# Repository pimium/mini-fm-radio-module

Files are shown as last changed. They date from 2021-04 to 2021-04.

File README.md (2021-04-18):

# FM stereo receiver module


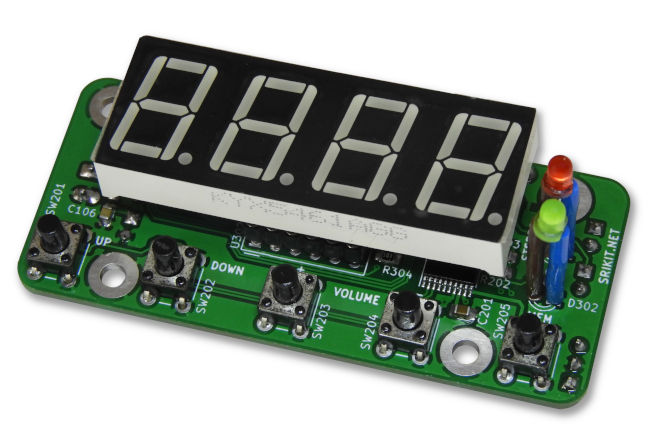
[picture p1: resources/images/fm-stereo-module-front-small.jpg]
KT0005


This is an RDA5807 based FM stereo radio module. This module is designed to replace old, low-voltage, analog FM stereo receiver modules. Like many digital receivers, this module also got auto scanning, station memory, and digital volume control. This module can driver using 5V to 9V DC power source.

The frequency range of the receiver is 88MHz to 108MHz. The auto scanner of this module can tune the receiver with 25kHz increments in up and down directions. 

The memory manager available with the current firmware can hold up to 10 stations in MCU EEPROM. 

AF output power of this module is not sufficient to handle the pair of speakers. To drive speakers, this module needs to pair with a stereo AF power amplifier kit/module.

This is an open-source hardware project. All the design files, [documentation](https://github.com/srikit/mini-fm-radio-module/wiki), and firmware source code are available to download at the [project source repository](https://github.com/srikit/mini-fm-radio-module). Content of this project is distributed under the terms of the following license:

 - Hardware License: [CERN-OHL-W](https://opensource.org/CERN-OHL-W)
 - Software License: [GNU GPL 3.0](https://github.com/srikit/mini-fm-radio-module/blob/main/LICENSE)
 - Documentation License: [CC BY 4.0](https://creativecommons.org/licenses/by/4.0)

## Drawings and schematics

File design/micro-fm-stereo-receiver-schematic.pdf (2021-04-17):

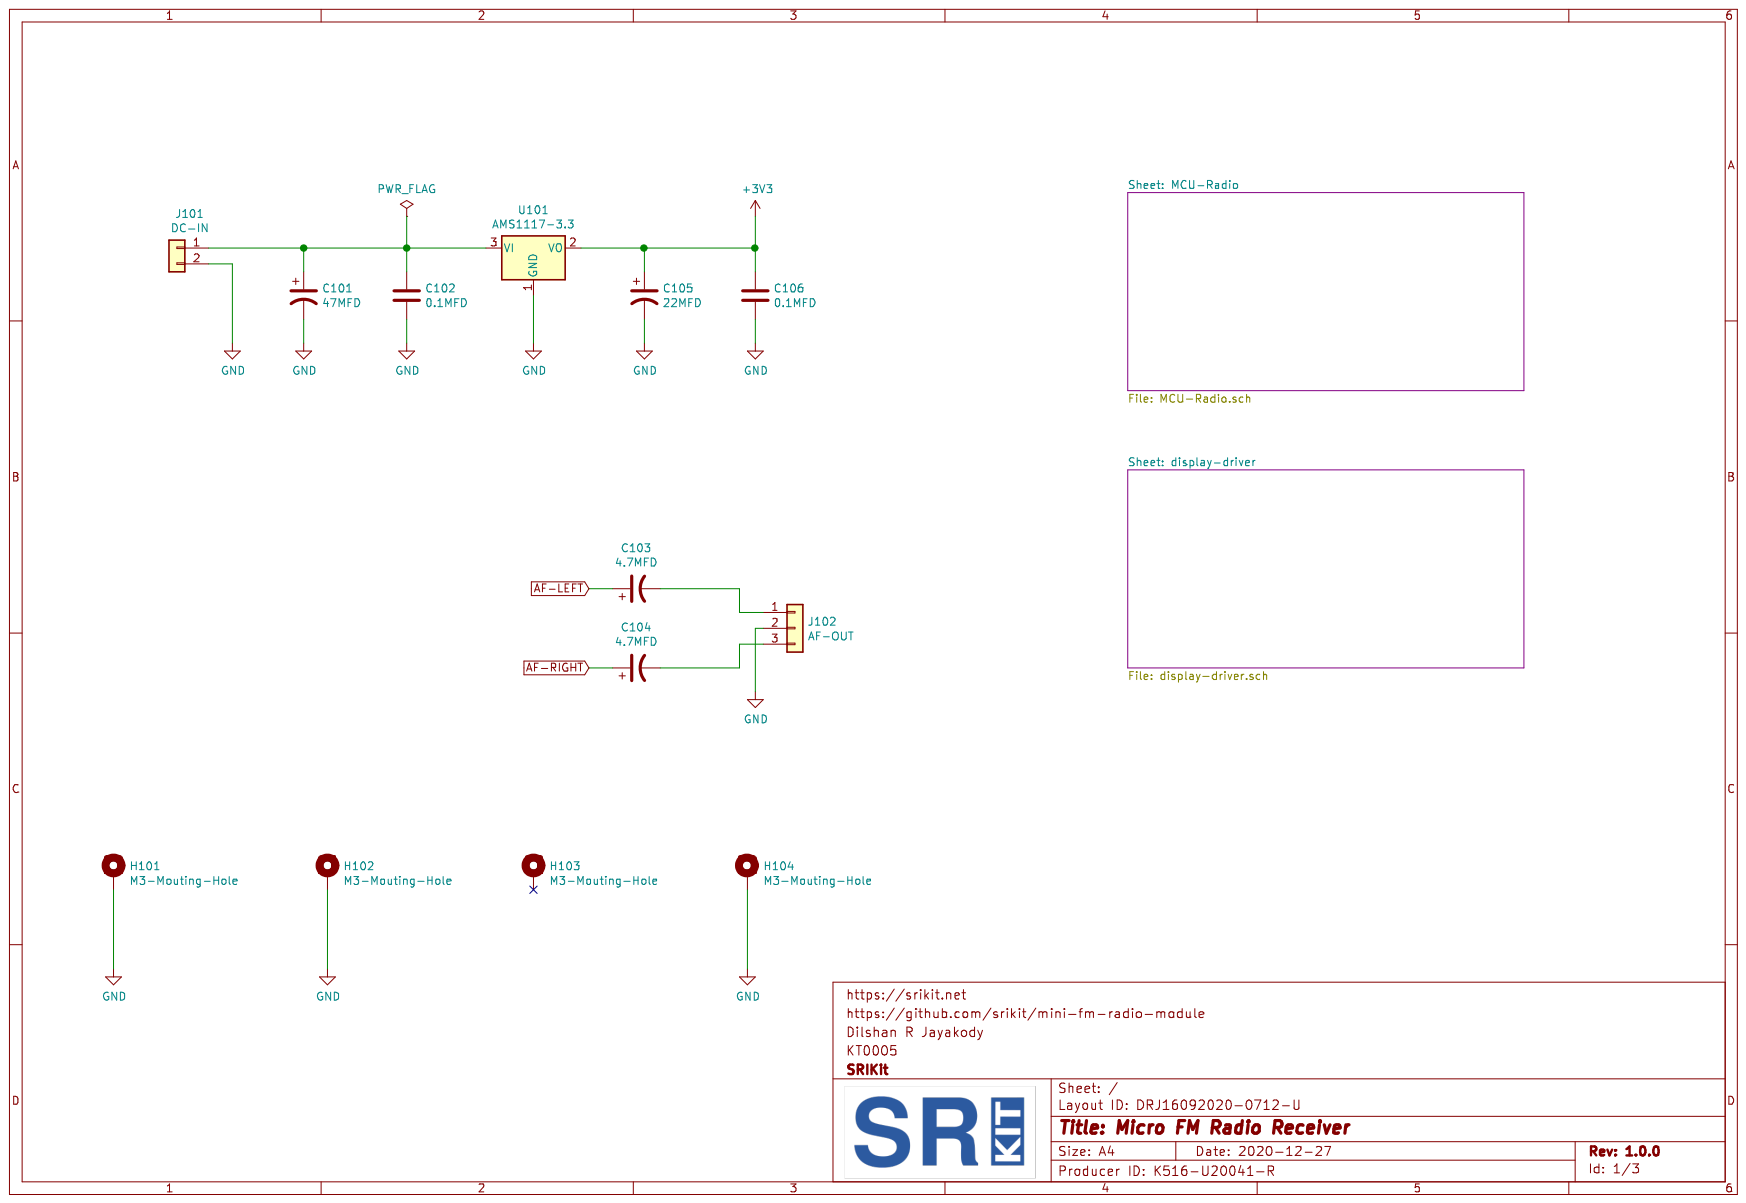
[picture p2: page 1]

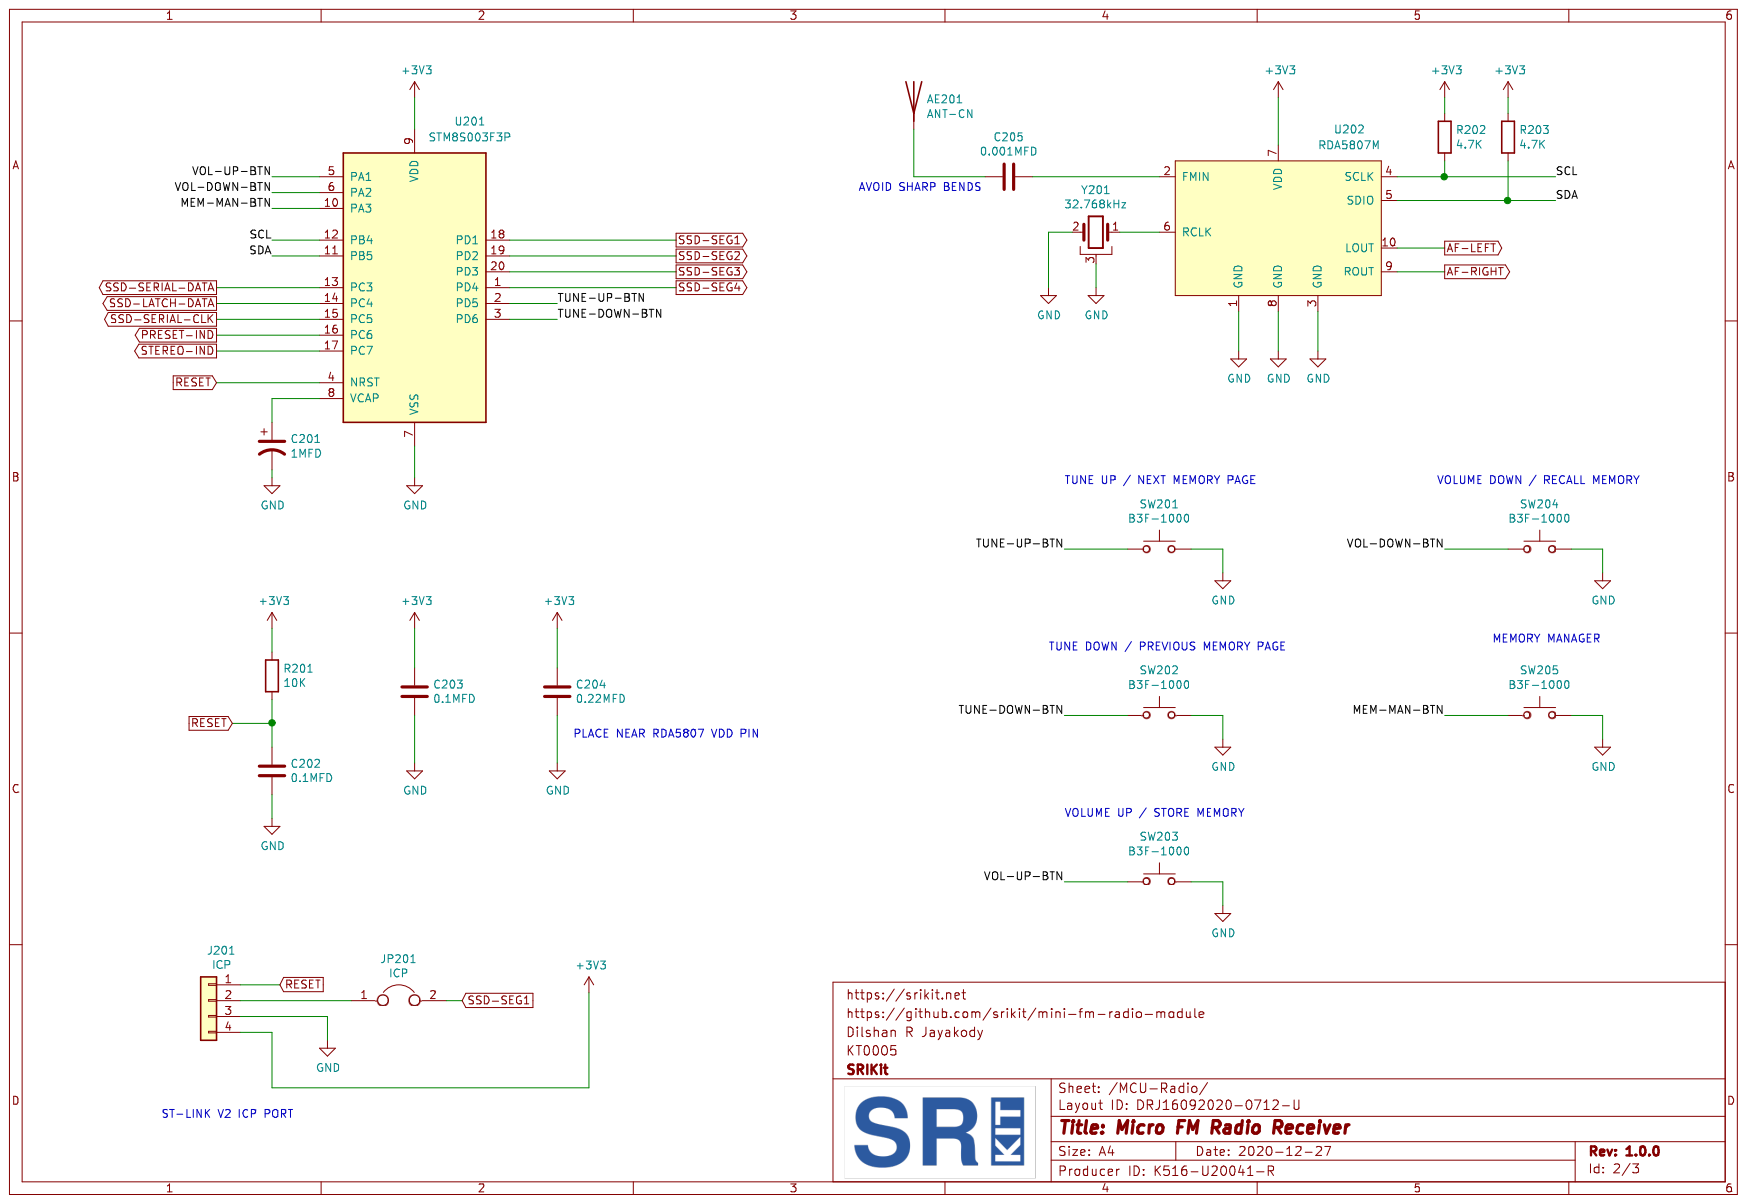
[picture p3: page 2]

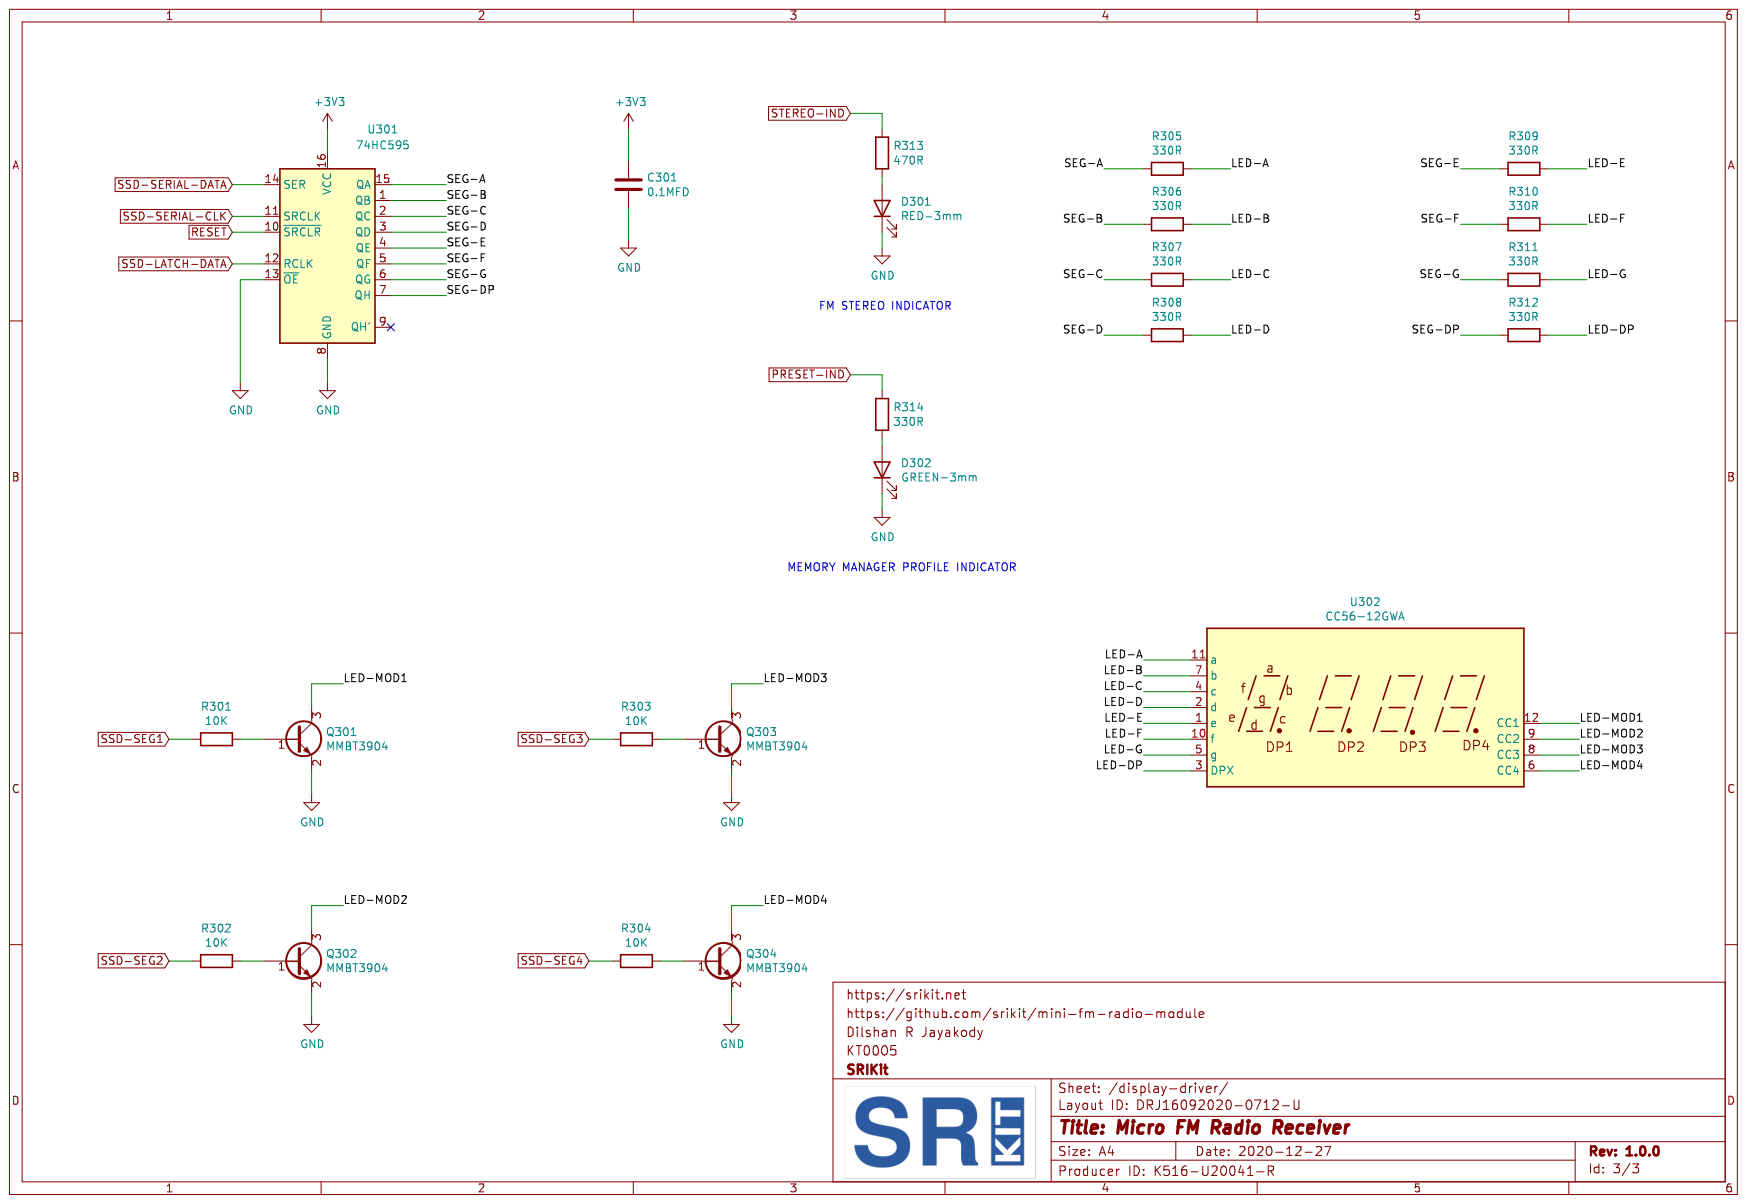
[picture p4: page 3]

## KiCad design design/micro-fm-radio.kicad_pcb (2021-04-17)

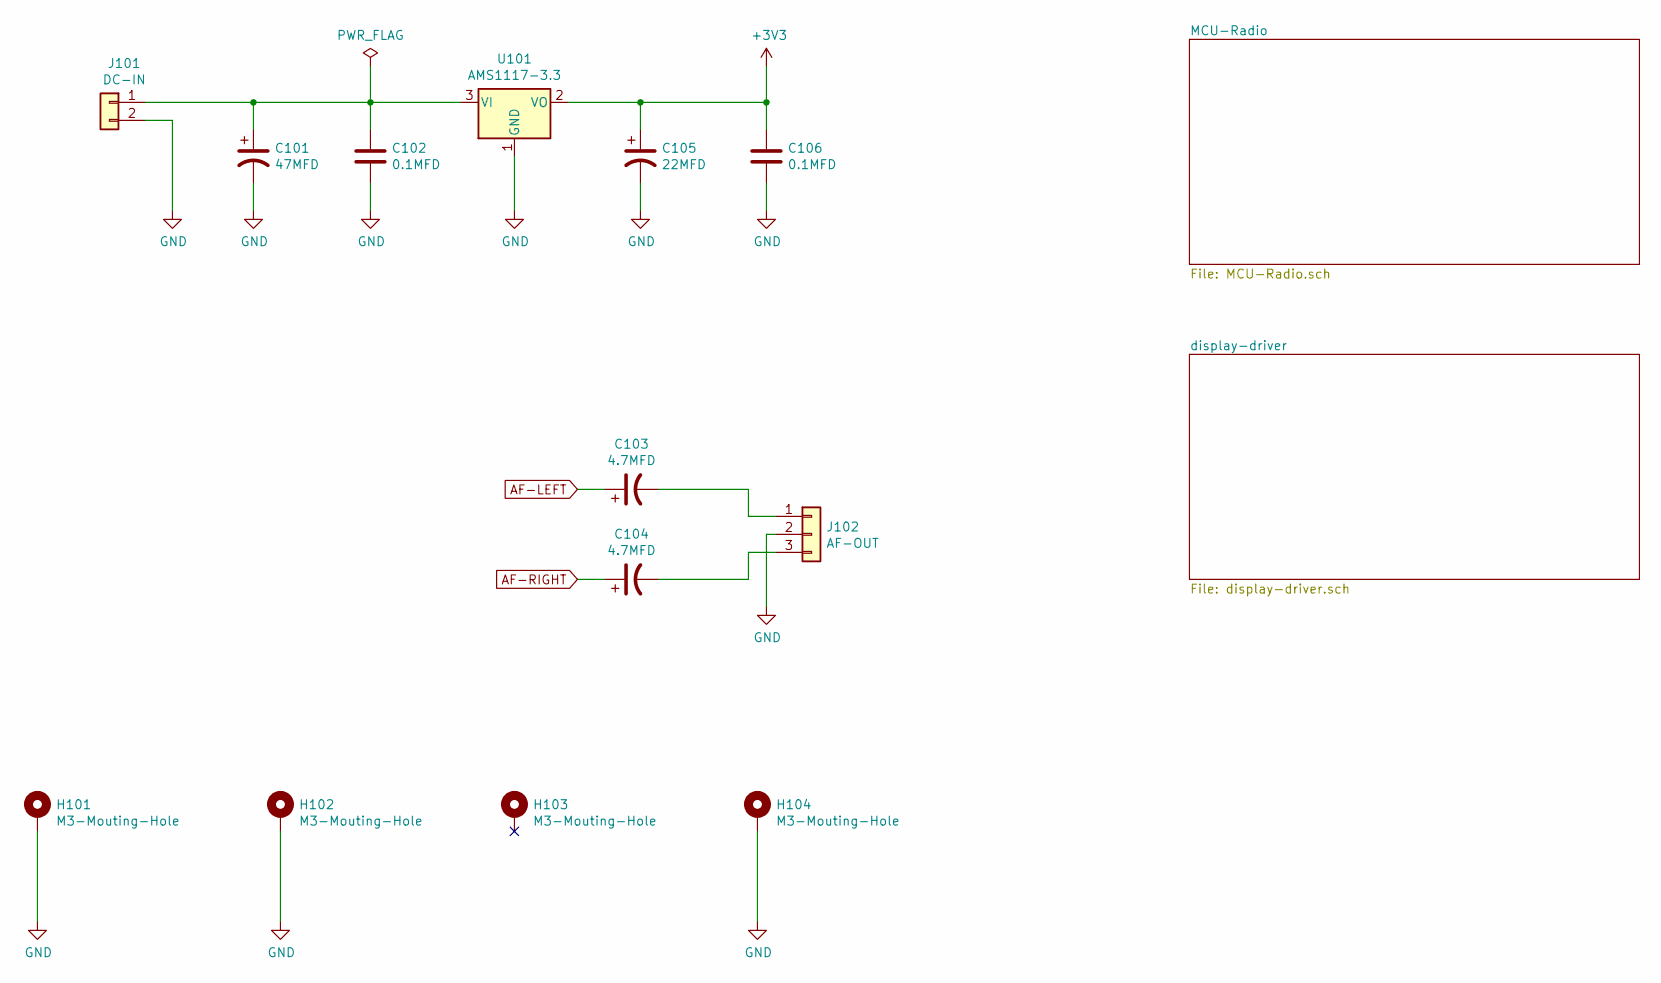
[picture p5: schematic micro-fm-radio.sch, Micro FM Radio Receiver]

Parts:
C101: 47MFD; CP_Radial_D5.0mm_P2.50mm
C102, C106: 0.1MFD; C_0805_2012Metric_Pad1.18x1.45mm_HandSolder
C103, C104: 4.7MFD; CP_Radial_D5.0mm_P2.50mm
C105: 22MFD; CP_Radial_D5.0mm_P2.50mm
H101, H102, H103, H104: M3-Mouting-Hole; MountingHole_3.2mm_M3_Pad
J101: DC-IN; PhoenixContact_MCV_1,5_2-G-3.5_1x02_P3.50mm_Vertical
J102: AF-OUT; PinHeader_1x03_P2.54mm_Vertical
U101: AMS1117-3.3; SOT-223-3_TabPin2

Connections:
+3V3: C105.1, C106.1, U101.2 (VO); also elsewhere on the board
AF-LEFT: C103.1; also elsewhere on the board
AF-RIGHT: C104.1; also elsewhere on the board
GND: C101.2, C102.2, C105.2, C106.2, H101.1, H102.1, H104.1, J101.2, J102.2, U101.1 (GND); also elsewhere on the board
unnamed: C101.1, C102.1, J101.1, U101.3 (VI)
unnamed: C103.2, J102.1
unnamed: C104.2, J102.3

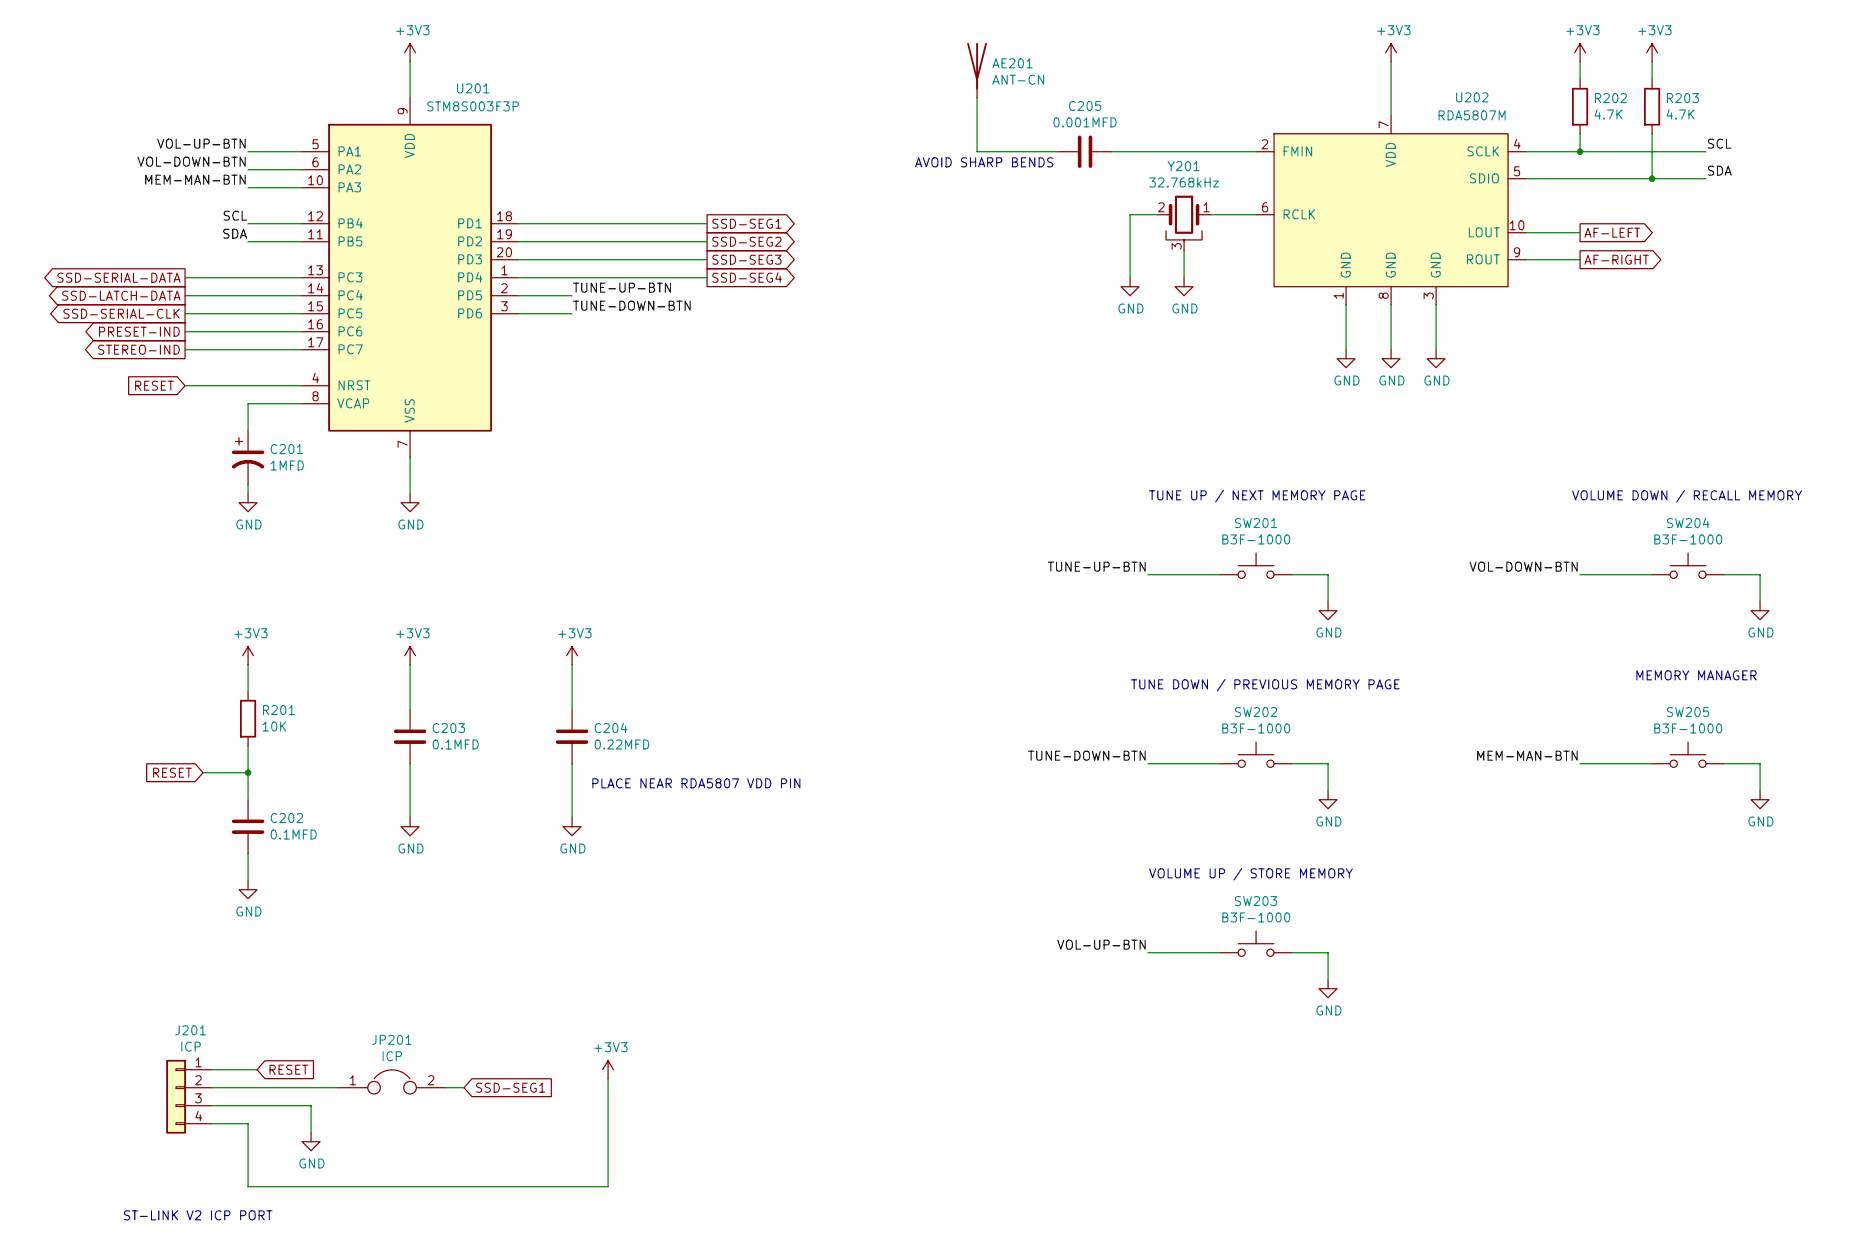
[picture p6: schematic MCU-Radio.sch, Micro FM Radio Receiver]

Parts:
AE201: ANT-CN; TestPoint_Loop_D2.50mm_Drill1.0mm
C201: 1MFD; C_0805_2012Metric_Pad1.18x1.45mm_HandSolder
C202, C203: 0.1MFD; C_0805_2012Metric_Pad1.18x1.45mm_HandSolder
C204: 0.22MFD; C_0805_2012Metric_Pad1.18x1.45mm_HandSolder
C205: 0.001MFD; C_0805_2012Metric_Pad1.18x1.45mm_HandSolder
J201: ICP; pogo-2.54mmx4
JP201: ICP; SolderJumper-2_P1.3mm_Bridged_Pad1.0x1.5mm
R201: 10K; R_0805_2012Metric_Pad1.20x1.40mm_HandSolder
R202, R203: 4.7K; R_0805_2012Metric_Pad1.20x1.40mm_HandSolder
SW201, SW202, SW203, SW204, SW205: B3F-1000; SW_PUSH_6mm
U201: STM8S003F3P; TSSOP-20_4.4x6.5mm_P0.65mm
U202: RDA5807M; MSOP-10_3x3mm_P0.5mm
Y201: 32.768kHz; Crystal_C38-LF_D3.0mm_L8.0mm_Horizontal_1EP_style2

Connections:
+3V3: C203.1, C204.1, J201.4, R201.1, R202.1, R203.1, U201.9 (VDD), U202.7 (VDD); also elsewhere on the board
/MCU-Radio/MEM-MAN-BTN: SW205.1, U201.10 (PA3)
/MCU-Radio/SCL: R202.2, U201.12 (PB4), U202.4 (SCLK)
/MCU-Radio/SDA: R203.2, U201.11 (PB5), U202.5 (SDIO)
/MCU-Radio/TUNE-DOWN-BTN: SW202.1, U201.3 (PD6)
/MCU-Radio/TUNE-UP-BTN: SW201.1, U201.2 (PD5)
/MCU-Radio/VOL-DOWN-BTN: SW204.1, U201.6 (PA2)
/MCU-Radio/VOL-UP-BTN: SW203.1, U201.5 (PA1)
AF-LEFT: U202.10 (LOUT); also elsewhere on the board
AF-RIGHT: U202.9 (ROUT); also elsewhere on the board
GND: C201.2, C202.2, C203.2, C204.2, J201.3, SW201.2, SW202.2, SW203.2, SW204.2, SW205.2, U201.7 (VSS), U202.1 (GND), U202.3 (GND), U202.8 (GND), Y201.2, Y201.3; also elsewhere on the board
unnamed: AE201.1, C205.2
unnamed: C201.1, U201.8 (VCAP)
unnamed: C205.1, U202.2 (FMIN)
unnamed: J201.2, JP201.1
unnamed: U202.6 (RCLK), Y201.1
PRESET-IND: U201.16 (PC6); also elsewhere on the board
RESET: C202.1, J201.1, R201.2, U201.4 (NRST); also elsewhere on the board
SSD-LATCH-DATA: U201.14 (PC4); also elsewhere on the board
SSD-SEG1: JP201.2, U201.18 (PD1); also elsewhere on the board
SSD-SEG2: U201.19 (PD2); also elsewhere on the board
SSD-SEG3: U201.20 (PD3); also elsewhere on the board
SSD-SEG4: U201.1 (PD4); also elsewhere on the board
SSD-SERIAL-CLK: U201.15 (PC5); also elsewhere on the board
SSD-SERIAL-DATA: U201.13 (PC3); also elsewhere on the board
STEREO-IND: U201.17 (PC7); also elsewhere on the board

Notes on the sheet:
PLACE NEAR RDA5807 VDD PIN
AVOID SHARP BENDS
TUNE UP / NEXT MEMORY PAGE
TUNE DOWN / PREVIOUS MEMORY PAGE
VOLUME UP / STORE MEMORY
VOLUME DOWN / RECALL MEMORY
MEMORY MANAGER
ST-LINK V2 ICP PORT

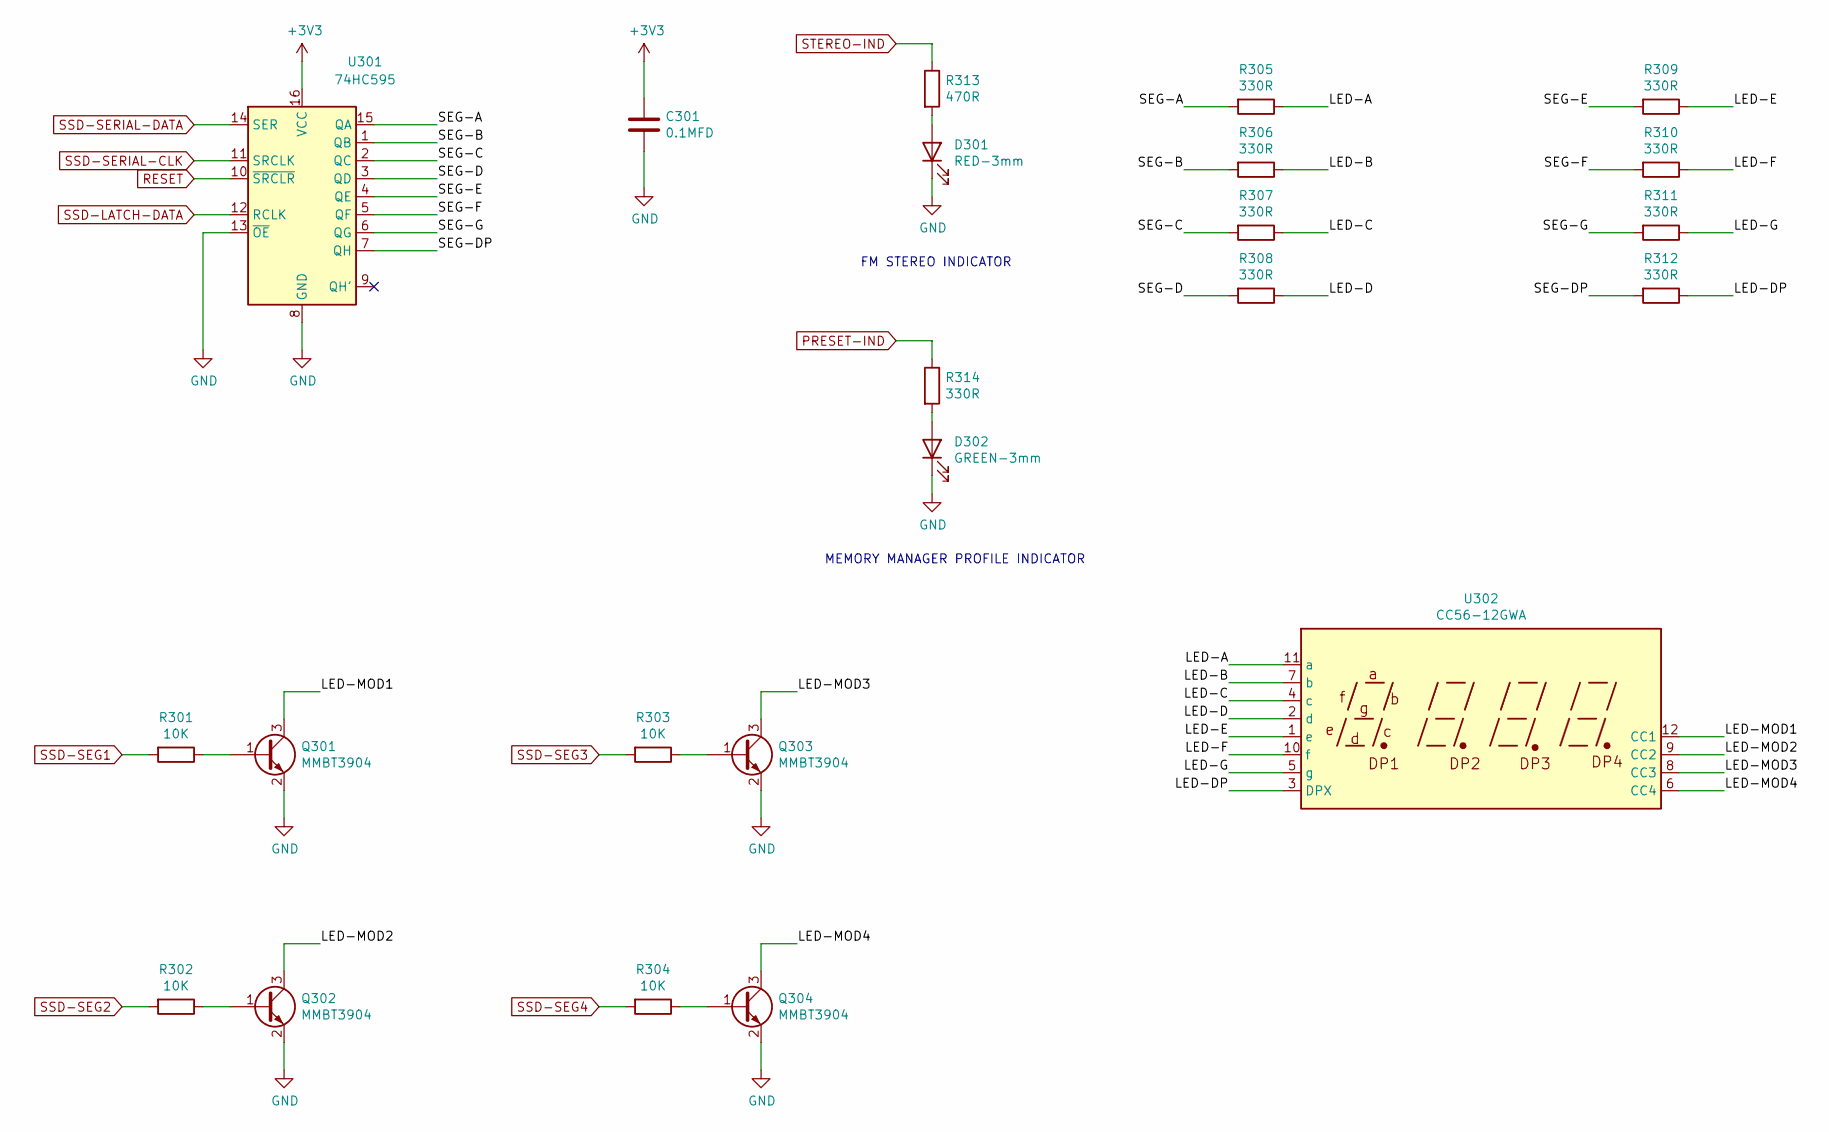
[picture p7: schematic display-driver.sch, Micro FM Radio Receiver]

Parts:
C301: 0.1MFD; C_0805_2012Metric_Pad1.18x1.45mm_HandSolder
D301: RED-3mm; LED_D3.0mm
D302: GREEN-3mm; LED_D3.0mm
Q301, Q302, Q303, Q304: MMBT3904; SOT-23
R301, R302, R303, R304: 10K; R_0805_2012Metric_Pad1.20x1.40mm_HandSolder
R305, R306, R307, R308, R309, R310, R311, R312, R314: 330R; R_0805_2012Metric_Pad1.20x1.40mm_HandSolder
R313: 470R; R_0805_2012Metric_Pad1.20x1.40mm_HandSolder
U301: 74HC595; SOP-16_4.4x10.4mm_P1.27mm
U302: CC56-12GWA

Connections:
+3V3: C301.1, U301.16 (VCC); also elsewhere on the board
/display-driver/LED-A: R305.1, U302.11 (a)
/display-driver/LED-B: R306.1, U302.7 (b)
/display-driver/LED-C: R307.1, U302.4 (c)
/display-driver/LED-D: R308.1, U302.2 (d)
/display-driver/LED-DP: R312.1, U302.3 (DPX)
/display-driver/LED-E: R309.1, U302.1 (e)
/display-driver/LED-F: R310.1, U302.10 (f)
/display-driver/LED-G: R311.1, U302.5 (g)
/display-driver/LED-MOD1: Q301.3 (C), U302.12 (CC1)
/display-driver/LED-MOD2: Q302.3 (C), U302.9 (CC2)
/display-driver/LED-MOD3: Q303.3 (C), U302.8 (CC3)
/display-driver/LED-MOD4: Q304.3 (C), U302.6 (CC4)
/display-driver/SEG-A: R305.2, U301.15 (QA)
/display-driver/SEG-B: R306.2, U301.1 (QB)
/display-driver/SEG-C: R307.2, U301.2 (QC)
/display-driver/SEG-D: R308.2, U301.3 (QD)
/display-driver/SEG-DP: R312.2, U301.7 (QH)
/display-driver/SEG-E: R309.2, U301.4 (QE)
/display-driver/SEG-F: R310.2, U301.5 (QF)
/display-driver/SEG-G: R311.2, U301.6 (QG)
GND: C301.2, D301.1 (K), D302.1 (K), Q301.2 (E), Q302.2 (E), Q303.2 (E), Q304.2 (E), U301.8 (GND), U301.13 (~OE); also elsewhere on the board
unnamed: D301.2 (A), R313.2
unnamed: D302.2 (A), R314.2
unnamed: Q301.1 (B), R301.1
unnamed: Q302.1 (B), R302.1
unnamed: Q303.1 (B), R303.1
unnamed: Q304.1 (B), R304.1
PRESET-IND: R314.1; also elsewhere on the board
RESET: U301.10 (~SRCLR); also elsewhere on the board
SSD-LATCH-DATA: U301.12 (RCLK); also elsewhere on the board
SSD-SEG1: R301.2; also elsewhere on the board
SSD-SEG2: R302.2; also elsewhere on the board
SSD-SEG3: R303.2; also elsewhere on the board
SSD-SEG4: R304.2; also elsewhere on the board
SSD-SERIAL-CLK: U301.11 (SRCLK); also elsewhere on the board
SSD-SERIAL-DATA: U301.14 (SER); also elsewhere on the board
STEREO-IND: R313.1; also elsewhere on the board

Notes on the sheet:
FM STEREO INDICATOR
MEMORY MANAGER PROFILE INDICATOR

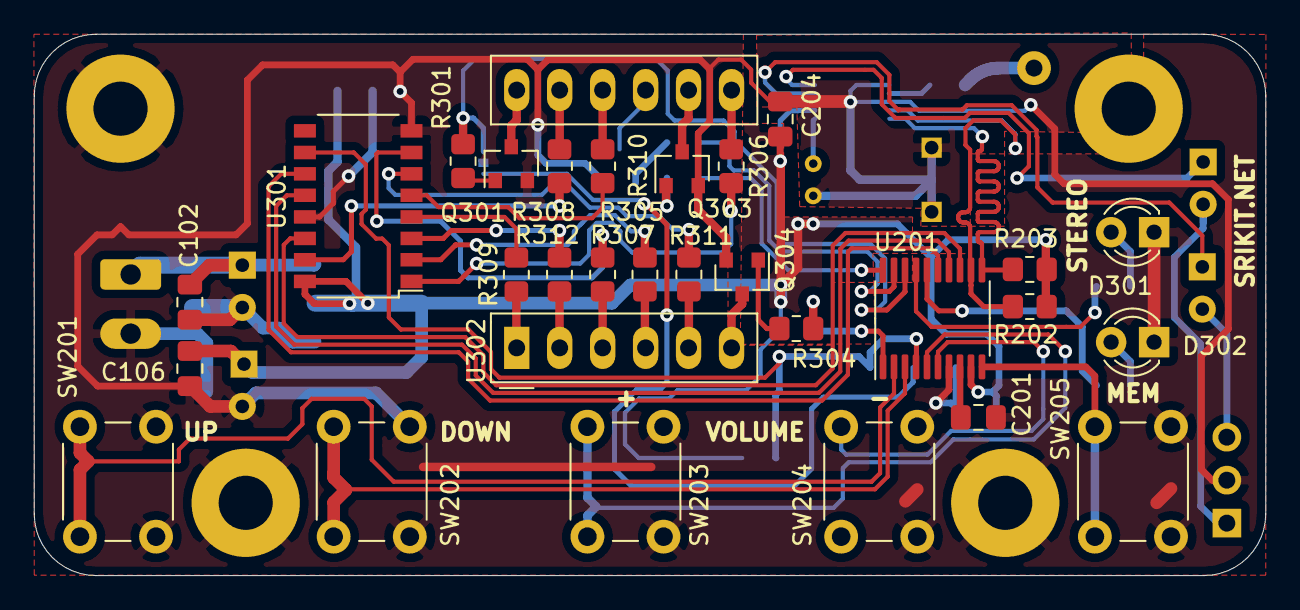
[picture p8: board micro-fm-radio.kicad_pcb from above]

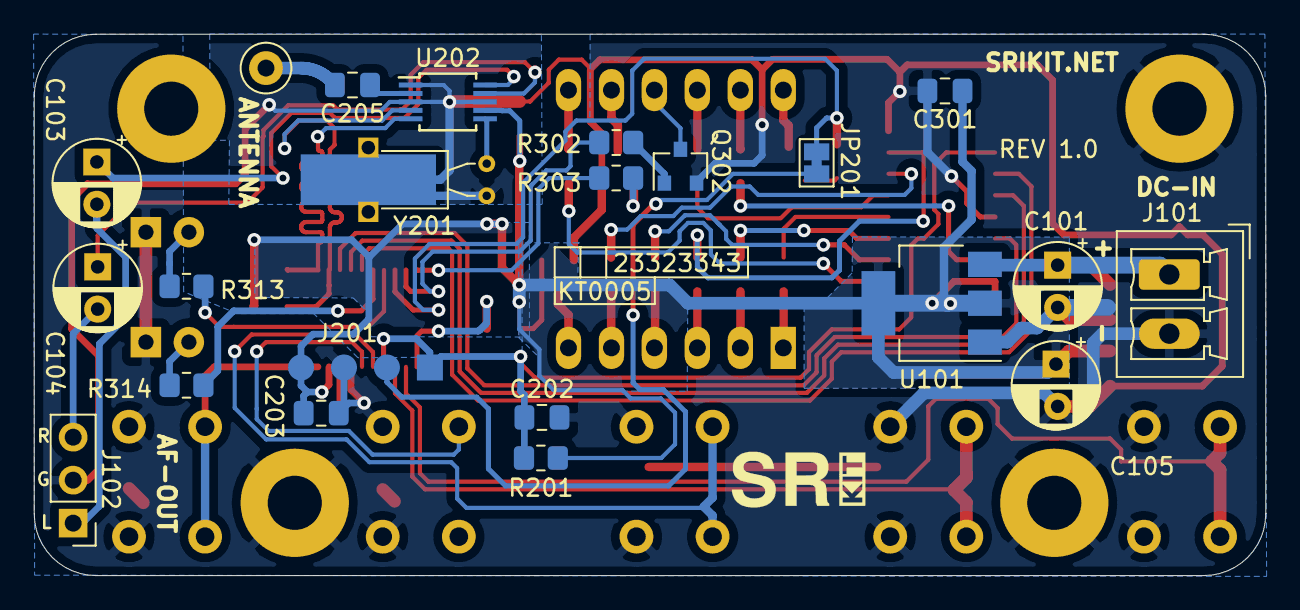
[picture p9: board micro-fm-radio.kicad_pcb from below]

Board: 2 copper layers, 72.8 x 32.0 mm, 55 parts (22 on the bottom side), 55 nets.

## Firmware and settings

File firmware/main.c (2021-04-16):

//-----------------------------------------------------------------------------
// Micro FM radio module firmware for STM8S003F3P6.
// Main source file.
//
// Copyright (C) 2020 SriKIT contributors.
//
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
// Last updated: Dilshan Jayakody [26th Dec 2020]
//
// Update log:
// [26/12/2020] - Initial version - Dilshan Jayakody.
//-----------------------------------------------------------------------------

#include "include/stm8.h"
#include "include/stm8-util.h"
#include "include/stm8-eeprom.h"

#include "main.h"
#include "serialssd.h"
#include "rda5807m.h"

#define CLEAR_SSD_DECIMAL   0x00
#define SET_SSD_DECIMAL     0x80

#define MAX_VOLUME_LEVEL    0x10

// The maximum allowed station numbers are 19.
#define MAX_STATION_NUMBER  10
#define MIN_STATION_NUMBER  1

#define EEPROM_VOLUME_ADDRESS   (EEPROM_START_ADDR + 1)
#define EEPROM_TUNE_CHANNEL_ADDRESS   (EEPROM_START_ADDR + 2)
#define EEPROM_MEM_MANAGER_BASE   (EEPROM_START_ADDR + 4)

void TIM2_update() __interrupt(TIMER2_TRIGGER_IRQ)
{
    // Set value of the first digit.
    PD_ODR &= 0xE1;
    setDigitValue(getDigitValue(displayValue[0], 1));
    PD_ODR |= 0x02;
    delay_cycle(300);

    // Set value of the second digit.
    PD_ODR &= 0xE1;
    setDigitValue(getDigitValue(displayValue[1], 0));
    PD_ODR |= 0x04;
    delay_cycle(300);

    // Set value of the third digit.
    PD_ODR &= 0xE1;
    setDigitValue(getDigitValue(displayValue[2], 0) | displayDecimal);
    PD_ODR |= 0x08;
    delay_cycle(290);

    // Set value of the fourth digit.
    PD_ODR &= 0xE1;
    setDigitValue(getDigitValue(displayValue[3], 0));
    PD_ODR |= 0x10;
    delay_cycle(300);

    // Shutdown all segments.
    PD_ODR &= 0xE1;

    // Clear timer 2 interrupt flag.
    TIM2_SR1 &= ~TIM2_SR1_UIF;
}

void main()
{
    unsigned char buttonState;
    unsigned short tunerChannel;
    unsigned char animCycle;
    unsigned char memoryManagerStation;
    
    cli();

    // Initialize MCU peripherals and global variables.
    initSystem();
    delay_ms(40);

    // Activate display control timer (Timer2).
    initDisplayTimer();

    // Load last volume level from EEPROM.
    volumeLevel = eepromRead(EEPROM_VOLUME_ADDRESS);
    if(volumeLevel > MAX_VOLUME_LEVEL)
    {
        // Volume setting is invalid or first time load.
        volumeLevel = 0;
    }

    // Load last saved station from EEPROM.
    tunerChannel = getSavedTunerChannel();
    if(tunerChannel > 0x3FF)
    {
        // Tuner channel is invalid or first time load.
        tunerChannel = 0;
    }

    // Start seven segment display panel.
    sei();
    delay_ms(20);
 
    // Display startup animation (to provide time to initialize RDA5807M).
    animCycle = 0;
    while(animCycle < 18)
    {
        switch (animCycle % 6)
        {
        case 0:
            displayValue[0] = 0x2E;
            displayValue[1] = 0xFF;
            displayValue[2] = 0xFF;
            displayValue[3] = 0xFF;
            break;
        case 1:
        case 5:
            displayValue[0] = 0xFF;
            displayValue[1] = 0x2E;
            displayValue[2] = 0xFF;
            displayValue[3] = 0xFF;
            break;
        case 2:
        case 4:
            displayValue[0] = 0xFF;
            displayValue[1] = 0xFF;
            displayValue[2] = 0x2E;
            displayValue[3] = 0xFF;
            break;
        case 3:        
            displayValue[0] = 0xFF;
            displayValue[1] = 0xFF;
            displayValue[2] = 0xFF;
            displayValue[3] = 0x2E;
            break;
        }

        delay_ms(60);
        animCycle++;
    }

    // End of the startup animation by shutting down all the segments.
    displayValue[0] = 0xFF;
    displayValue[1] = 0xFF;
    displayValue[2] = 0xFF;
    displayValue[3] = 0xFF;
    delay_ms(100);

    // Initialize RDA5807M receiver.
    initRDAFMReceiver(volumeLevel, tunerChannel);

    buttonState = (PD_IDR & 0x60) | (PA_IDR & 0x0E);
    displayDecimal = SET_SSD_DECIMAL;
    memoryManagerStation = 1;

    // Get receiver information.
    getReceiverConfig(RECEIVER_READ_CONFIG_LEN);
    getTunerFrequency(displayValue);

    // Main service loop.
    while(1)
    {
        // Check for UP button event.
        if(((PD_IDR & 0x20) == 0x20) && ((buttonState & 0x20) == 0x00))
        {
            // Save any pending volume level changes.
            if(currentMode == mdVolume)
            {
                // Save new volume level in EEPROM.
                if(eepromRead(EEPROM_VOLUME_ADDRESS) != volumeLevel)
                {
                    eepromWrite(EEPROM_VOLUME_ADDRESS, volumeLevel);
                }
            }
            
            // UP button press is detected.
            displayDecimal = SET_SSD_DECIMAL;
            currentMode = mdFreq;

            // Set modeResetCounter to raise EEPROM save function.
            modeResetCounter = 1;

            seekChannel(0);
        }

        // Check for DOWN button event.
        if(((PD_IDR & 0x40) == 0x40) && ((buttonState & 0x40) == 0x00))
        {
            // Save any pending volume level changes.
            if(currentMode == mdVolume)
            {
                // Save new volume level in EEPROM.
                if(eepromRead(EEPROM_VOLUME_ADDRESS) != volumeLevel)
                {
                    eepromWrite(EEPROM_VOLUME_ADDRESS, volumeLevel);
                }
            }
            
            // DOWN button press is detected.
            displayDecimal = SET_SSD_DECIMAL;
            currentMode = mdFreq;

            // Set modeResetCounter to raise EEPROM save function.
            modeResetCounter = 1;

            seekChannel(1);
        }

        // Check for volume UP button event.
        if(((PA_IDR & 0x02) == 0x02) && ((buttonState & 0x02) == 0x00))
        {
            // Save any pending frequency changes.
            if((currentMode == mdFreq) && (modeResetCounter > 0))
            {
                // Save pending frequency changes into EEPROM.
                modeResetCounter = 0;
                getTunerChannel(&tunerChannel);

                if(tunerChannel != getSavedTunerChannel())
                {
                    // Save channel into EEPROM.
                    eepromWrite(EEPROM_TUNE_CHANNEL_ADDRESS, ((tunerChannel >> 8) & 0xFF));
                    eepromWrite((EEPROM_TUNE_CHANNEL_ADDRESS + 1), (tunerChannel & 0xFF));
                }
            }
            
            // Volume UP button press is detected.            
            volumeLevel = volumeLevel + ((volumeLevel == MAX_VOLUME_LEVEL) ? 0 : 1);
            displayDecimal = CLEAR_SSD_DECIMAL;
            currentMode = mdVolume;
            modeResetCounter = 0;

            setVolumeOnDisplay();
            setRDAVolume(volumeLevel);
        }

        // Check for volume DOWN button event.
        if(((PA_IDR & 0x04) == 0x04) && ((buttonState & 0x04) == 0x00))
        {
            // Save any pending frequency changes.
            if((currentMode == mdFreq) && (modeResetCounter > 0))
            {
                // Save pending frequency changes into EEPROM.
                modeResetCounter = 0;
                getTunerChannel(&tunerChannel);

                if(tunerChannel != getSavedTunerChannel())
                {
                    // Save channel into EEPROM.
                    eepromWrite(EEPROM_TUNE_CHANNEL_ADDRESS, ((tunerChannel >> 8) & 0xFF));
                    eepromWrite((EEPROM_TUNE_CHANNEL_ADDRESS + 1), (tunerChannel & 0xFF));
                }
            }
            
            // Volume DOWN button press is detected.
            volumeLevel = volumeLevel - ((volumeLevel == 0) ? 0 : 1);               
            displayDecimal = CLEAR_SSD_DECIMAL;
            currentMode = mdVolume;
            modeResetCounter = 0;        

            setVolumeOnDisplay();
            setRDAVolume(volumeLevel);            
        }

        // Check for memory manager button event.
        if(((PA_IDR & 0x08) == 0x08) && ((buttonState & 0x08) == 0x00))
        {
            // Save any pending frequency changes.
            if((currentMode == mdFreq) && (modeResetCounter > 0))
            {
                // Save pending frequency changes into EEPROM.
                modeResetCounter = 0;
                getTunerChannel(&tunerChannel);

                if(tunerChannel != getSavedTunerChannel())
                {
                    // Save channel into EEPROM.
                    eepromWrite(EEPROM_TUNE_CHANNEL_ADDRESS, ((tunerChannel >> 8) & 0xFF));
                    eepromWrite((EEPROM_TUNE_CHANNEL_ADDRESS + 1), (tunerChannel & 0xFF));
                }
            }            
            else
            {
                // Save any pending volume level changes.
                if(eepromRead(EEPROM_VOLUME_ADDRESS) != volumeLevel)
                {
                    eepromWrite(EEPROM_VOLUME_ADDRESS, volumeLevel);
                }
            }
            
            // Get current channel from the tuner.
            modeResetCounter = 0;
            getTunerChannel(&tunerChannel);

            // Activate memory manager.
            if(memoryManager(&memoryManagerStation, &tunerChannel))
            {
                // Station has been recall by the memory manager.
                setTunerFrequency(tunerChannel);
                delay_ms(50);

                // Set modeResetCounter to raise EEPROM save function.
                modeResetCounter = 1;
            }   

            // Reset preset indicator flag to perform force scan on memory manager's channels.
            lastCheckChannel = 0xFFFF;

            // Return to frequency mode.
            getReceiverConfig(RECEIVER_READ_CONFIG_LEN);
            getTunerFrequency(displayValue);
            displayDecimal = SET_SSD_DECIMAL;
            currentMode = mdFreq;
        }

        buttonState = (PD_IDR & 0x60) | (PA_IDR & 0x0E);
        
        // Get current frequency and status data from the RDA receiver.
        getReceiverConfig(RECEIVER_READ_CONFIG_LEN);

        // Update stereo indicator.
        if(isStereoChannel())
        {
            // Stereo channel.
            PC_ODR |= 0x80;
        }
        else
        {
            // Mono channel.
            PC_ODR &= 0x7F;
        }

        // Control preset channel indicator (to identify saved channels).
        if(isStation())
        {
            getTunerChannel(&tunerChannel);
            isPresetChannel(&tunerChannel);
        }
        else
        {
            // Shutdown preset channel indicator because current channel is not a station.
            PC_ODR &= 0xBF;
        }
                
        // Reset mode counter.
        if(currentMode == mdVolume)
        {                        
            // System is in volume mode.
            if((++modeResetCounter) > MODE_RESET_TIME)
            {
                // Save new volume level in EEPROM.
                if(eepromRead(EEPROM_VOLUME_ADDRESS) != volumeLevel)
                {
                    eepromWrite(EEPROM_VOLUME_ADDRESS, volumeLevel);
                }
                
                // Mode timeout reached and set system (display) mode to Frequency Mode.
                modeResetCounter = 0;
                displayDecimal = SET_SSD_DECIMAL;
                currentMode = mdFreq;
            }
        }
        else
        {
            // System is in Frequency mode.            
            getTunerFrequency(displayValue);

            // If channel is changed, check for save timeout.
            if(modeResetCounter > 0)
            {
                if((++modeResetCounter) > TUNER_SAVE_TIME)
                {
                    // Channel save timeout is reached.
                    modeResetCounter = 0;
                    getTunerChannel(&tunerChannel);

                    if(tunerChannel != getSavedTunerChannel())
                    {
                        // Save channel into EEPROM.
                        eepromWrite(EEPROM_TUNE_CHANNEL_ADDRESS, ((tunerChannel >> 8) & 0xFF));
                        eepromWrite((EEPROM_TUNE_CHANNEL_ADDRESS + 1), (tunerChannel & 0xFF));
                    }
                }
            }
        } 

        delay_cycle(190);           
    }
}

void initSystem()
{
    // PC3 [OUT] : Serial data.
    // PC4 [OUT] : Latch data.
    // PC5 [OUT] : Serial clock.
    // PC6 [OUT] : Channel available in memory manager indicator (Preset channel).
    // PC7 [OUT] : Stereo indicator.
    PC_ODR = 0x00;
    PC_DDR = 0xF8;
    PC_CR1 = 0xF8;
    PC_CR2 = 0x00;  

    // PD1 [OUT] : Seven segment digit 1 driver.
    // PD2 [OUT] : Seven segment digit 2 driver.
    // PD3 [OUT] : Seven segment digit 3 driver.
    // PD4 [OUT] : Seven segment digit 4 driver. 
    // PD5 [IN]  : UP button.
    // PD6 [IN]  : DOWN button.
    PD_ODR = 0x00; 
    PD_DDR = 0x1E;
    PD_CR1 = 0x7E;
    PD_CR2 = 0x00;

    // PA1 [IN] : Volume UP button.
    // PA2 [IN] : Volume Down button.
    // PA3 [IN] : Memory.
    PA_DDR = 0x00;
    PA_CR1 = 0x0E;
    PA_CR2 = 0x00;

    // Initialize global variables.
    displayDecimal = CLEAR_SSD_DECIMAL;
    currentMode = mdFreq;
    modeResetCounter = 0;
    volumeLevel = 0;    
    lastCheckChannel = 0xFFFF;
}

void initDisplayTimer()
{
    // Set timer 2 prescaler to 256.
    TIM2_PSCR = 8;

    // Set ARRH to get ms interrupt.
    TIM2_ARRH = 0x00;
    TIM2_ARRL = 0x27;

    // Enable timer 2 interrupt.
    TIM2_IER |= TIM2_IER_UIE;
    TIM2_CR1 |= TIM2_CR1_CEN;
}

void setVolumeOnDisplay()
{
    // First two digits are always off in this mode.
    displayValue[0] = 0xFF;
    displayValue[1] = 0xFF;
    displayValue[2] = ((volumeLevel / 10) ? 1 : 0xFF);
    displayValue[3] = volumeLevel % 10;
}

unsigned short getSavedTunerChannel()
{
    return ((unsigned short)eepromRead(EEPROM_TUNE_CHANNEL_ADDRESS) << 8) | (eepromRead(EEPROM_TUNE_CHANNEL_ADDRESS + 1));
}

unsigned char memoryManager(unsigned char *stationNumber, unsigned short *channel)
{   
    unsigned char buttonState;
    unsigned short memAddr;
    unsigned short idleCounter;
    
    // Display "S" for memory manager station.
    displayDecimal = CLEAR_SSD_DECIMAL;
    displayValue[0] = 5;
    displayValue[1] = 0xFF;

    buttonState = (PD_IDR & 0x60) | (PA_IDR & 0x0E);
    idleCounter = 0;

    while(1)
    {
        // Display current station number.
        displayValue[2] = (((*stationNumber) == MAX_STATION_NUMBER) ? 1 : 0xFF);
        displayValue[3] = (*stationNumber) % 10;

        // Check for UP button event.
        if(((PD_IDR & 0x20) == 0x20) && ((buttonState & 0x20) == 0x00))
        {
            (*stationNumber) = ((*stationNumber) >= MAX_STATION_NUMBER) ? MIN_STATION_NUMBER : ((*stationNumber) + 1);
            idleCounter = 0;
        }

        // Check for DOWN button event.
        if(((PD_IDR & 0x40) == 0x40) && ((buttonState & 0x40) == 0x00))
        {
            (*stationNumber) = ((*stationNumber) == MIN_STATION_NUMBER) ? MAX_STATION_NUMBER : ((*stationNumber) - 1);
            idleCounter = 0;
        }

        // Check for STORE button event.
        if(((PA_IDR & 0x02) == 0x02) && ((buttonState & 0x02) == 0x00))
        {
            memAddr = EEPROM_MEM_MANAGER_BASE + ((*stationNumber) * 2);
            eepromWrite(memAddr, (((*channel) >> 8) & 0xFF));
            eepromWrite((memAddr + 1), ((*channel) & 0xFF));
            return 0;
        }

        // Check for RECALL button event.
        if(((PA_IDR & 0x04) == 0x04) && ((buttonState & 0x04) == 0x00))
        {
            memAddr = EEPROM_MEM_MANAGER_BASE + ((*stationNumber) * 2);
            (*channel) = ((unsigned short)eepromRead(memAddr) << 8) | (eepromRead(memAddr + 1));

            if((*channel) > 0x3FF)
            {
                // Tuner channel is invalid or first time load.
                (*channel) = 0;
            }

            delay_ms(100);
            return 1;
        }

        // Check for memory manager button event.
        if(((PA_IDR & 0x08) == 0x08) && ((buttonState & 0x08) == 0x00))
        {
            delay_ms(60);
            return 0;
        }

        // Check for memory manager idle timeout.
        if((++idleCounter) > MEM_MANAGER_IDLE_TIME)
        {
            // Memory manager idle timeout is reached.
            return 0;
        }

        buttonState = (PD_IDR & 0x60) | (PA_IDR & 0x0E);

        // Get current frequency and status data from the RDA receiver.
        getReceiverConfig(RECEIVER_READ_CONFIG_LEN);

        // Update stereo indicator.
        if(isStereoChannel())
        {
            // Stereo channel.
            PC_ODR |= 0x80;
        }
        else
        {
            // Mono channel.
            PC_ODR &= 0x7F;
        }

        delay_cycle(280); 
    }
}

void isPresetChannel(unsigned short *currentChannel)
{
    unsigned char scanPos = MAX_STATION_NUMBER;
    unsigned short memChannel;
    unsigned short memAddr;

    if((*currentChannel) != (lastCheckChannel))
    {
        // Current channel is different from the last checked channel.
        lastCheckChannel = (*currentChannel);

        while(scanPos > (MIN_STATION_NUMBER - 1))
        {
            // Extract saved frequency from the memory solt.
            memAddr = EEPROM_MEM_MANAGER_BASE + (scanPos * 2);
            memChannel = ((unsigned short)eepromRead(memAddr) << 8) | (eepromRead(memAddr + 1));
            
            // Check for identical channel data.
            if(memChannel == lastCheckChannel)
            {
                // Saved channel and current channel are identical.
                break;
            }

            // Move to next memory slot.
            scanPos--;
        }

        if(scanPos != 0)
        {
            // Loop is terminated in the middle, so given channel is available.
            PC_ODR |= 0x40;
        }
        else
        {
            // Given channel is not available in memory manager.
            PC_ODR &= 0xBF;
        }        
    }
}

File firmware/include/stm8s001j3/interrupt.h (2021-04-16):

//-----------------------------------------------------------------------------
// STM8S001J3 IRQ mapping header file for SDCC.
//
// Copyright (C) 2020 SriKIT contributors.
//
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
// Based on STM8S001J3 datasheet DS12129 Rev 4.
// Last updated: Dilshan Jayakody [1st Nov 2020]
//
// Update log:
// [01/11/2020] - Initial version - Dilshan Jayakody.
//-----------------------------------------------------------------------------

#ifndef STM8S001_INTERRUPT_MAP_H
#define STM8S001_INTERRUPT_MAP_H

#define EXTERNAL_TOP_LEVEL_IRQ      0       // External top level interrupt.
#define AUTO_WAKE_HALT_IRQ          1       // Auto wake up from halt.

#define CLK_IRQ                     2       // Clock controller.

#define PORTA_IRQ                   3       // Port A external interrupts.
#define PORTB_IRQ                   4       // Port B external interrupts.
#define PORTC_IRQ                   5       // Port C external interrupts.
#define PORTD_IRQ                   6       // Port D external interrupts.
#define PORTE_IRQ                   7       // Port E external interrupts.

#define SPI_END_TRANSFER_IRQ        10      // SPI end of transfer.

#define TIMER1_TRIGGER_IRQ          11      // TIMER1 update/overflow/underflow/trigger/break.
#define TIMER1_COMPARE_IRQ          12      // TIMER1 capture/compare.

#define TIMER2_TRIGGET_IRQ          13      // TIMER2 update /overflow.
#define TIMER2_COMPARE_IRQ          14      // TIMER2 capture/compare.

#define UART1_TX_IRQ                17      // UART1 TX (send) complete.
#define UART1_RX_IRQ                18      // UART1 RX (receive) register is full.

#define IIC_IRQ                     19      // I2C interrupt.

#define ADC1_COMPLETE_IRQ           22      // ADC1 end of conversion/analog watchdog interrupt.

#define TIMER4_TRIGGET_IRQ          23      // TIMER4 update/overflow.

#define FLASH_IRQ                   24      // Flash memory end of operation / WR_PG_DIS.

#endif /* STM8S001_INTERRUPT_MAP_H */

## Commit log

2021-04-16 Initial version of firmware, design files and prototype images.
    [MCU-Radio.sch, display-driver.sch, micro-fm-radio.kicad_pcb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]
2021-04-16 Add PDF version of the schematic.
2021-04-17 Fix value of C205 capacitor. Add project ID to the readme.md file.
    [MCU-Radio.sch, PAM8403-sketch.fzz, micro-fm-radio.kicad_pcb]

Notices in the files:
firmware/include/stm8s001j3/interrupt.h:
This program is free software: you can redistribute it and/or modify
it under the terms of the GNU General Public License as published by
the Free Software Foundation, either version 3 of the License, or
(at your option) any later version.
